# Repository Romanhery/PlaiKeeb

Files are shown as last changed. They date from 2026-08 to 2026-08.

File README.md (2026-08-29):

<h1>Plai-Keeb</h1>
Plai Keeb is a custom keyboard 75 % exploded keyboard with a rotary encoder and macro keys.
<h2>Features:</h2>
<ul>
   <li>Switched Rotary Encoder for volume control</li>
   <li>4 macro keys</li>
   <li>Candy Holder</li>
</ul>
<h2>PCB:</h2>
   <h2>Schematic</h2>
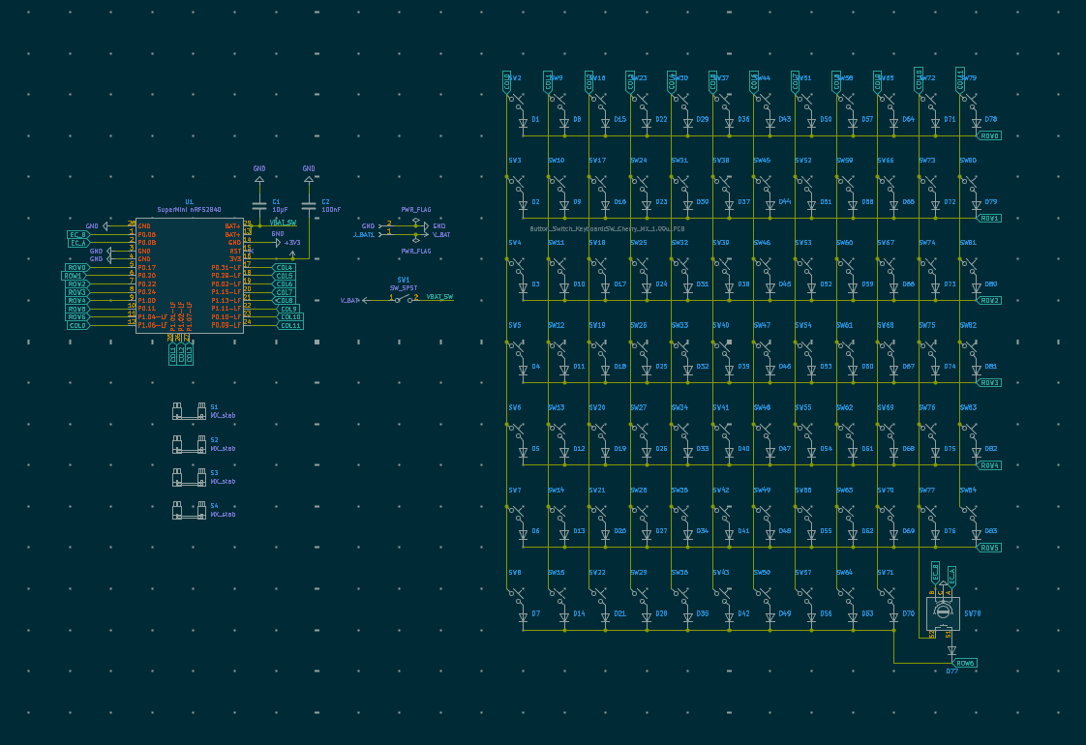
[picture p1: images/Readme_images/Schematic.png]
Schematic
   
   <h2>PCB</h2>
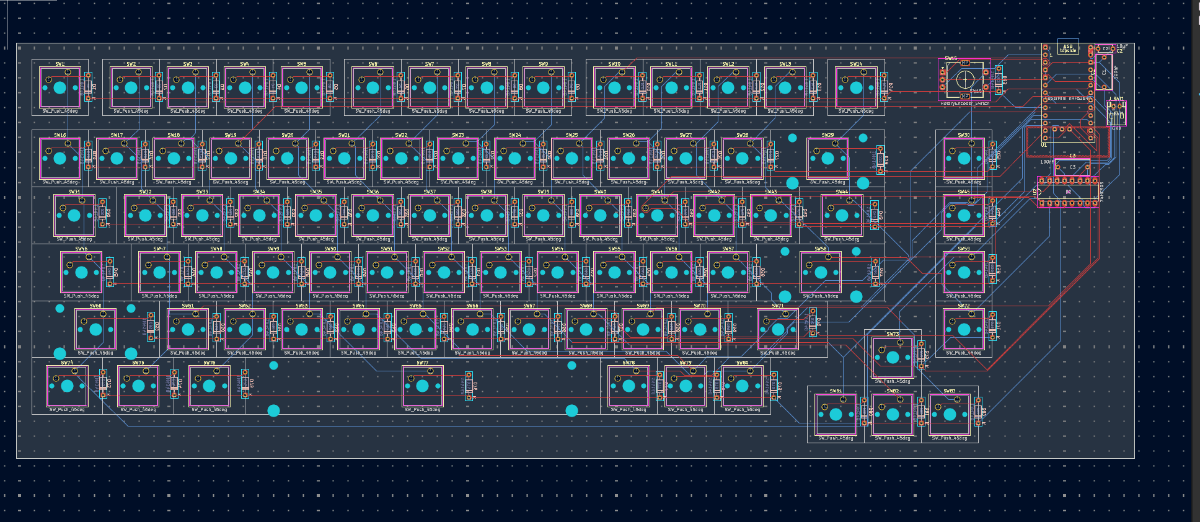
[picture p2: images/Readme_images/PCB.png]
PCB
   
   <p>Made in <a href="https://www.kicad.org/">Ki-CAD</a></p> 

<h2>CAD:</h2>
   <p>Everything is held together by using 6 M3 Bolts and heated inserts.</p>
   <p>It has 2 printed pieces and a plate to cover the electronics and house them.</p>
   <p>Made in Fusion 360</p>
<p align="center">
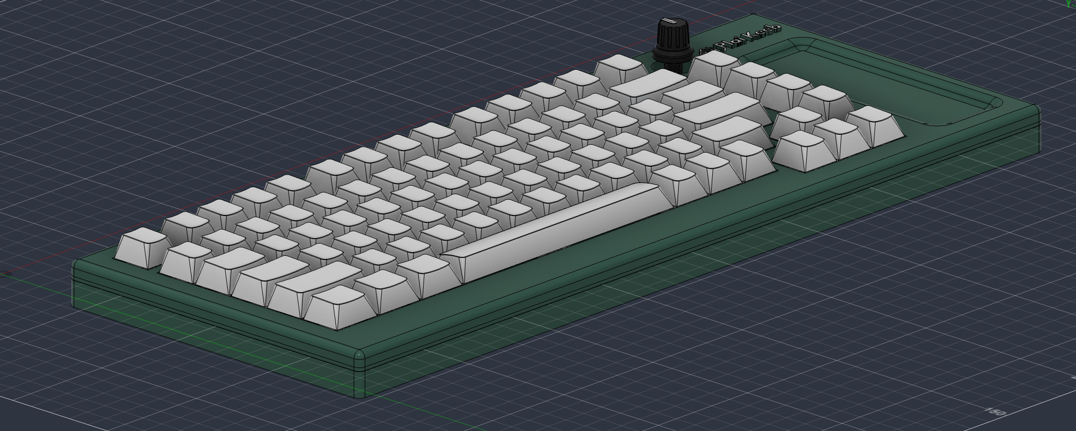
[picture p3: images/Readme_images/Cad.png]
Plai CAD Render
  
</p>
<h2>Firmware:</h2>
   <p>Made with <a href="https://github.com/KMKfw/kmk_firmware">KMK</a> firmware</p> 
   <h3>Features</h3>
   <li>Volume control if you twist the rotary encoder and if you press the encoder to mute</li>
   <li>It has macros for any shorcut you want!</li>
   <p align="center">
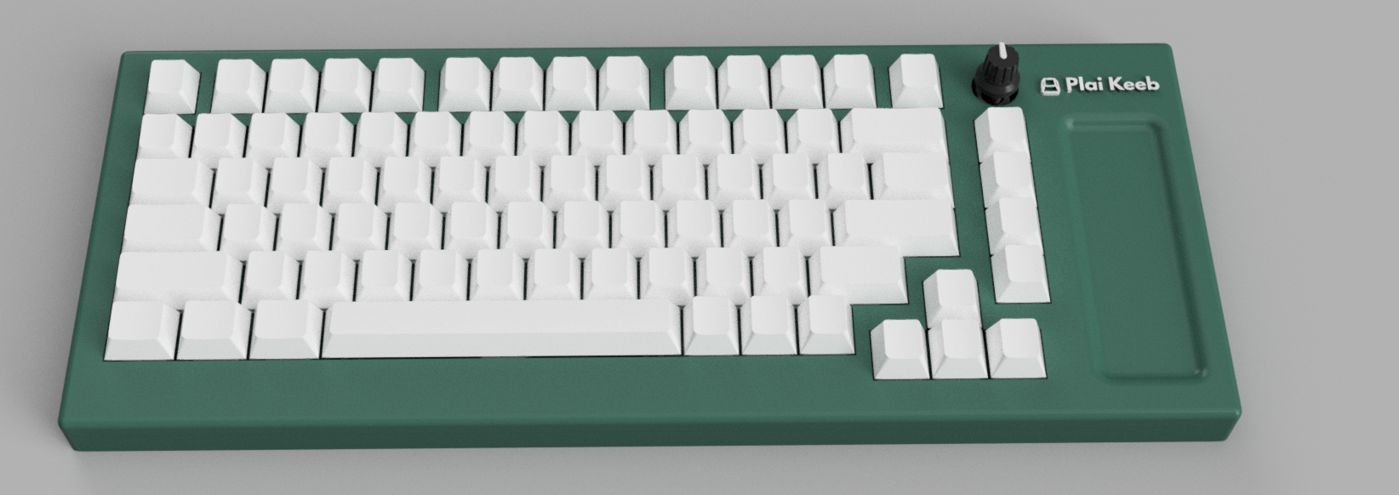
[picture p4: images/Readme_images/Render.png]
  
   </p>
<h2>BOM:</h2>
<p>Everything you need to make this macro pad is here!</p>
<ul>
    <li>9x Cherry MX Switches</li>
    <li>9x DSA Keycaps</li>
    <li>5x M3x5x4 Heatset inserts</li>
    <li>4x M3x16mm SHCS Bolts</li>
    <li>9x 1N4148 DO-35 Diodes.</li>
    <li>1x 0.91" OLED Display</li>
    <li>1x EC11 Rotary Encoder</li>
    <li>1x XIAO RP2040</li>
    <li>1x Case (2 printed parts)</li>
   <a href="https://docs.google.com/spreadsheets/d/1uIeMTGPOrdSAiFDxR4G393WpXhlTQVRrd_AwqsaPwl4/edit?usp=sharing">BOM HERE WITH LINKS</a>
</ul>
<h2>Acknowledgements</h2> 

* [Keeb](https://github.com/hackclub/hackpad/tree/main/cad/orpheuspad)
* [Void Pointer](https://github.com/Mirai-09/Keybie-Hackpads)
## Authors
- [@Romanhery](https://github.com/Romanhery)

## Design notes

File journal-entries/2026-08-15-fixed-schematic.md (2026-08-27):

# Fixed Schematic

📅 **2026-08-15** · 🕐 **23:03** · ⏱️ **1h logged**  

---
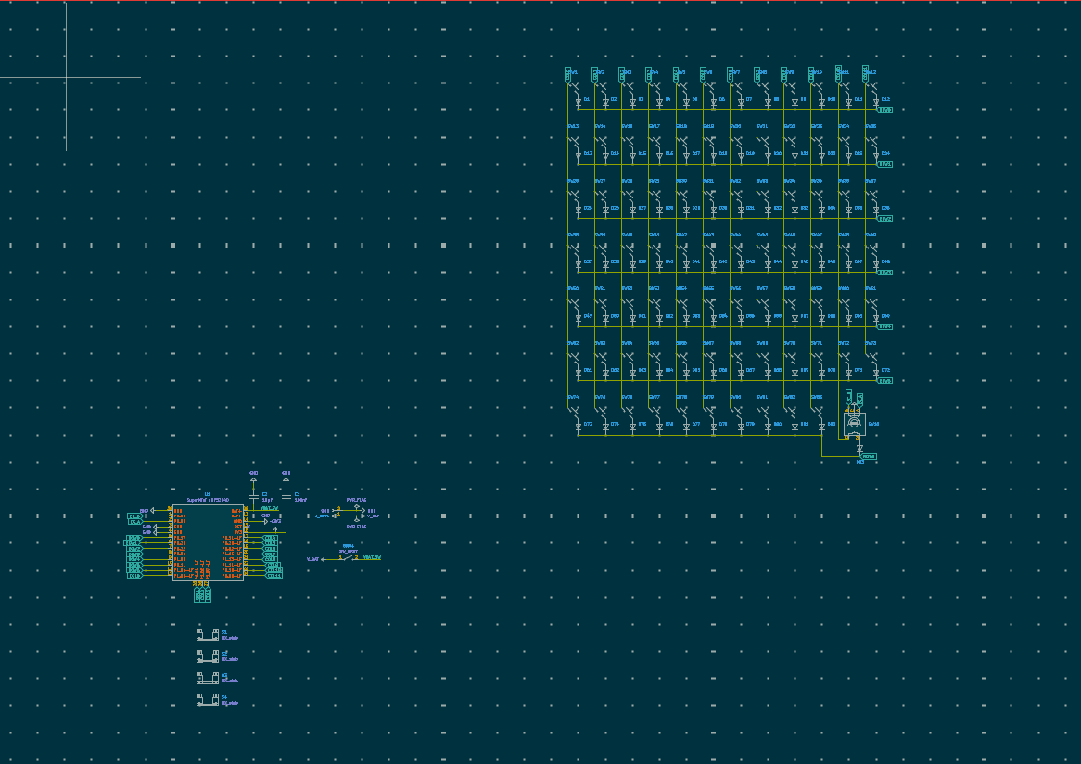
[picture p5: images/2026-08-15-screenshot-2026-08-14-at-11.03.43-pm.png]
Screenshot 2026-08-14 at 11.03.43 PM.png

I refactored the collumns and the rows so that they use 2 less pins which were what I needed instead of the hard to code shift register or io extender and I have more space on my keyboard too. I learned that sometimes you just need to go back the the fundementals and build that first better.

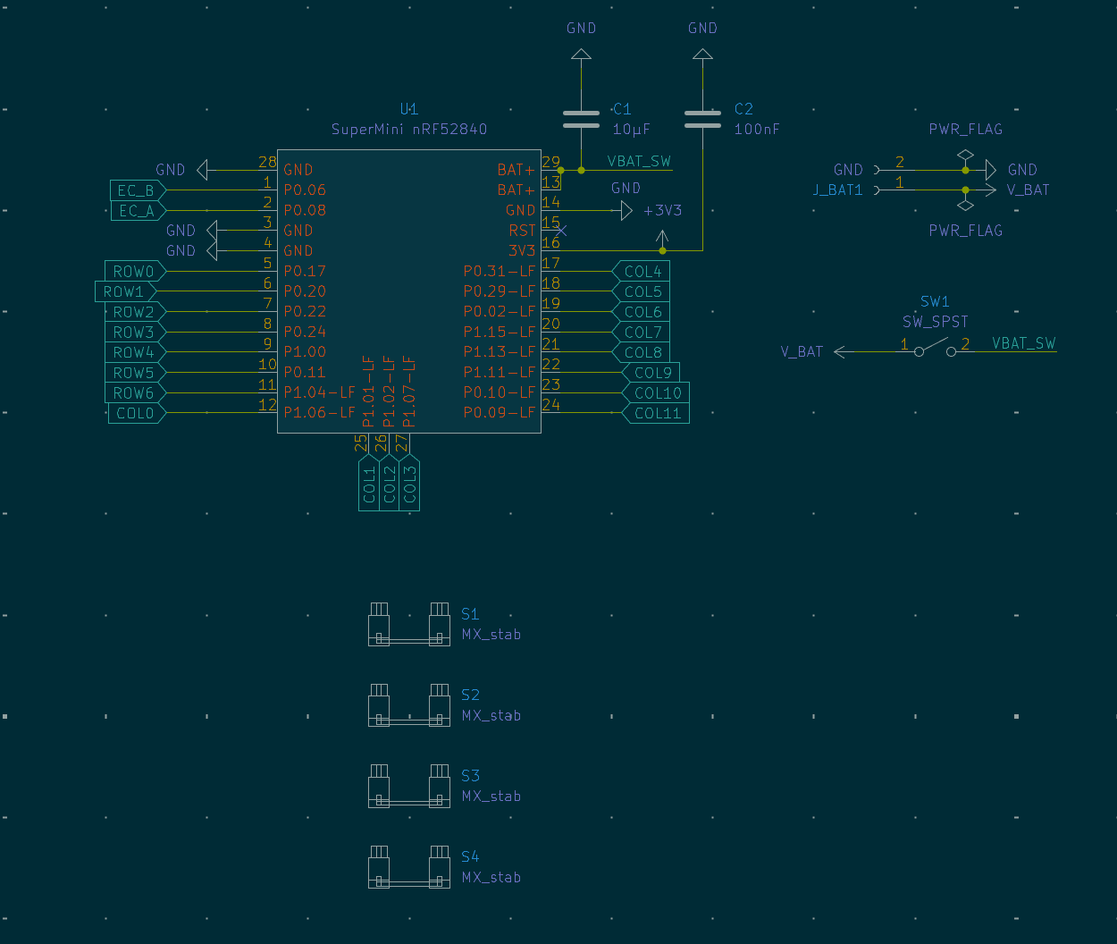
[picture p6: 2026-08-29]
images/Readme_images/Microcontroller.png

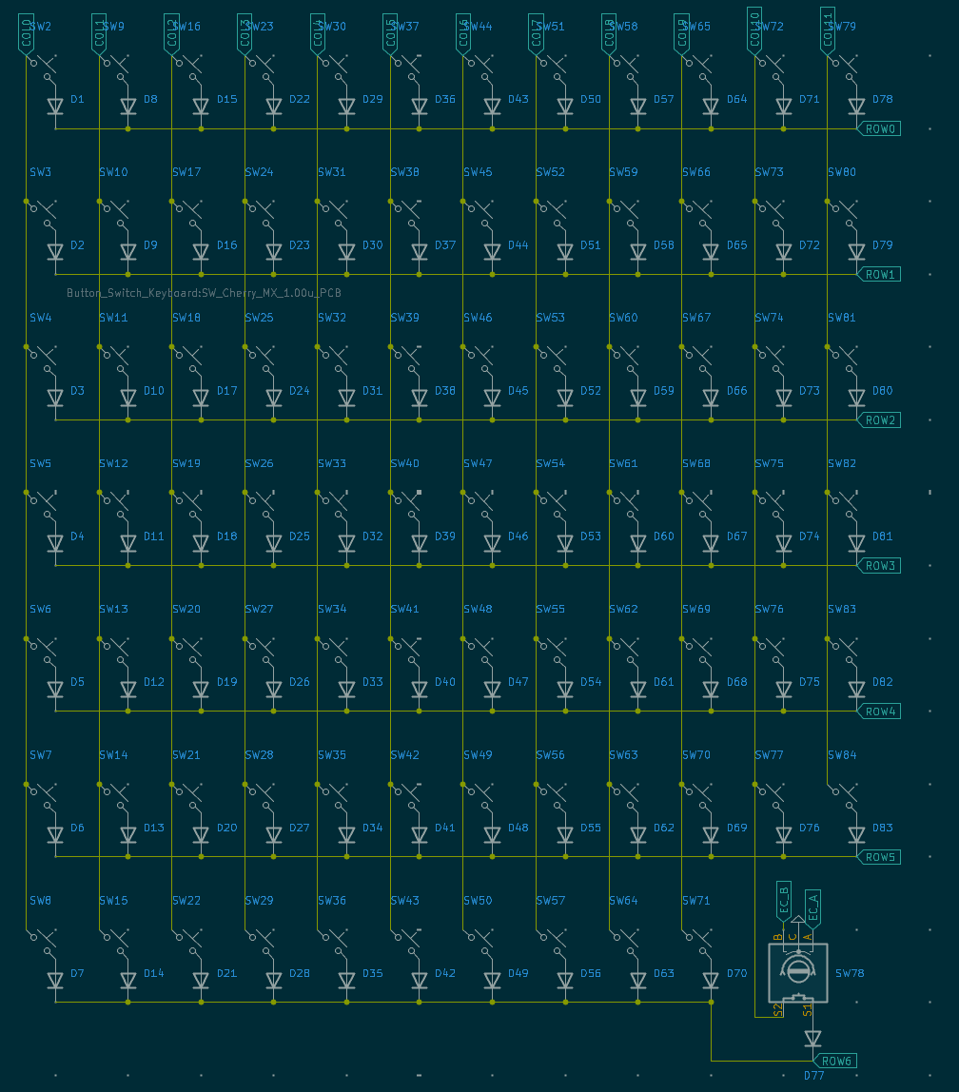
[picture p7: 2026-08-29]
images/Readme_images/Key_matrix.png

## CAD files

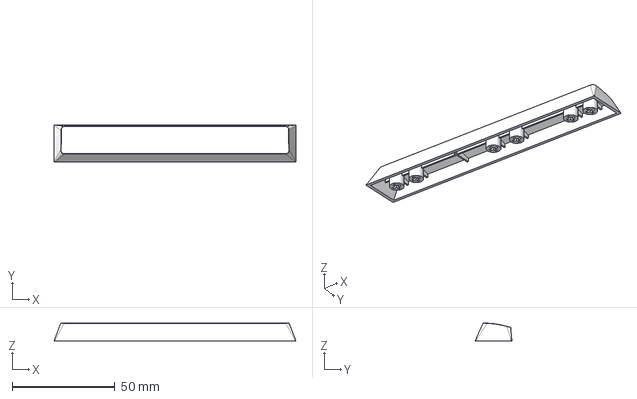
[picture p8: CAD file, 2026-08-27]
Case/3d-Models/6.25u keycap.step
118.0 x 18.0 x 8.70 mm

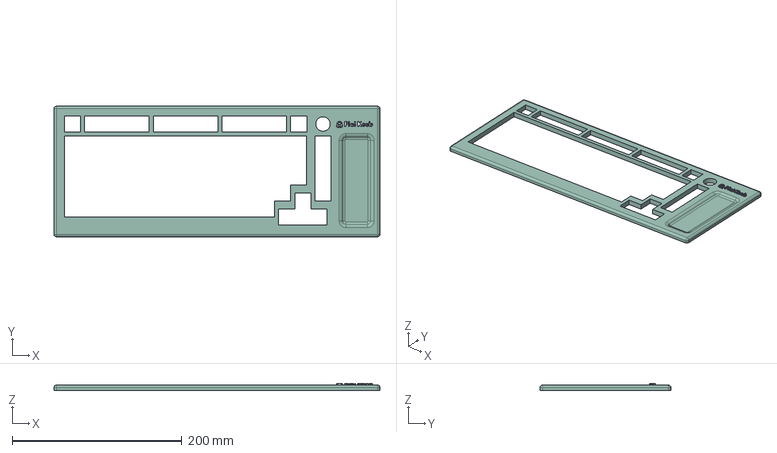
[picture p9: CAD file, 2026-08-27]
Case/Keeboard_Top_Cover.step
384.0 x 154.0 x 7.90 mm

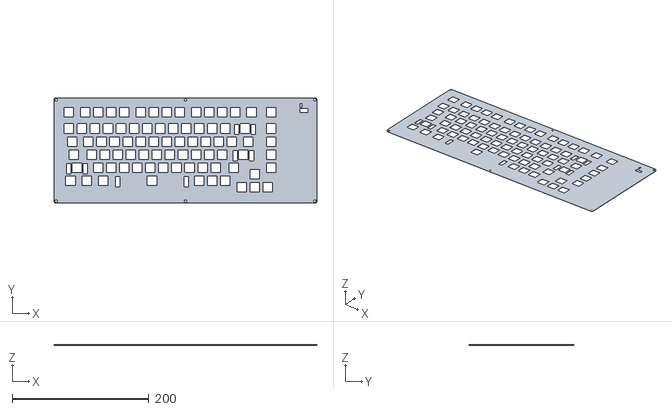
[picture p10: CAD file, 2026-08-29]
Production/Case_Production/Plate.stl
384.0 x 154.0 x 1.50

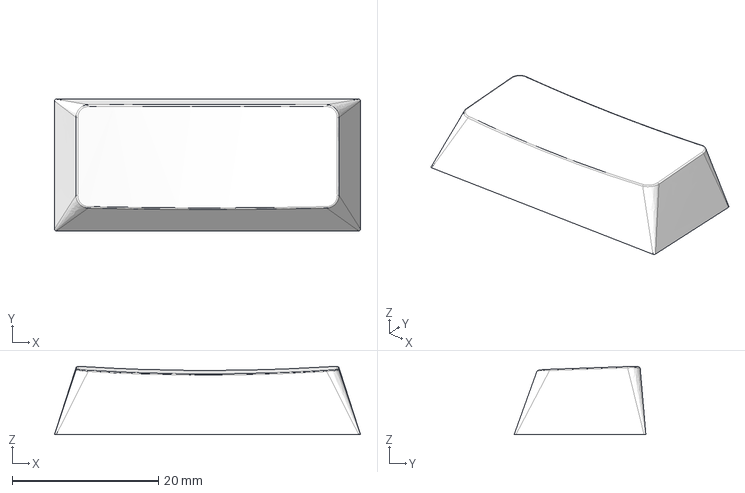
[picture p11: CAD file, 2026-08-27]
Case/3d-Models/2.25u keycap.step
41.8 x 18.0 x 9.30 mm

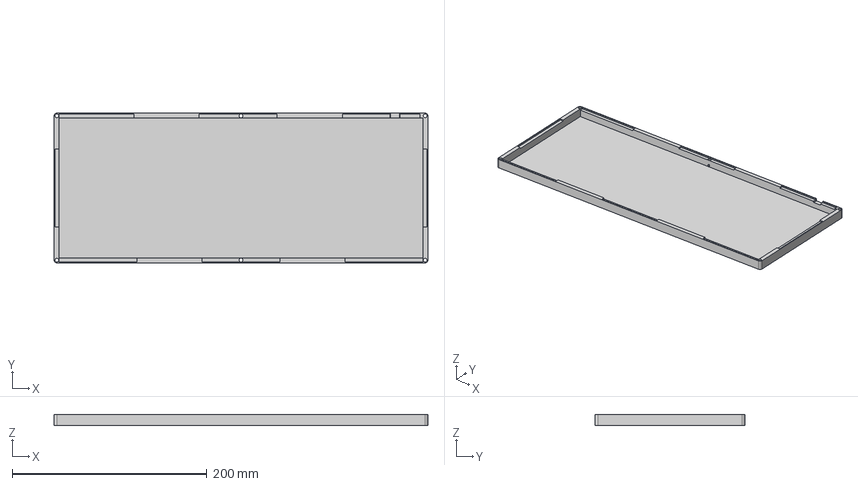
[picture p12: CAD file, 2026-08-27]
Case/Bottom_Case.step
384.0 x 154.0 x 11.0 mm

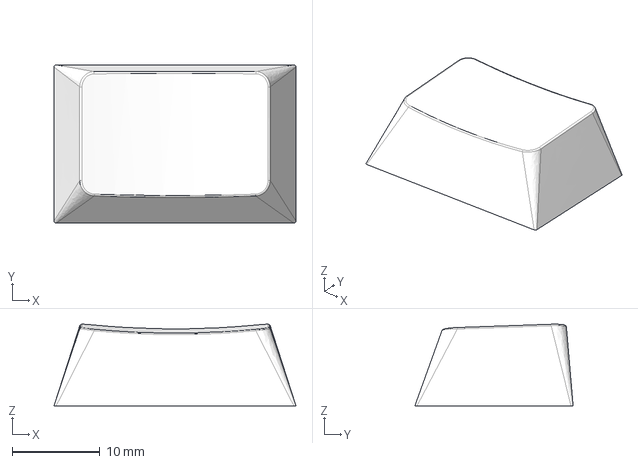
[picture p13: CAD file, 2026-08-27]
Case/3d-Models/1.5u keycap.step
27.5 x 18.0 x 9.28 mm

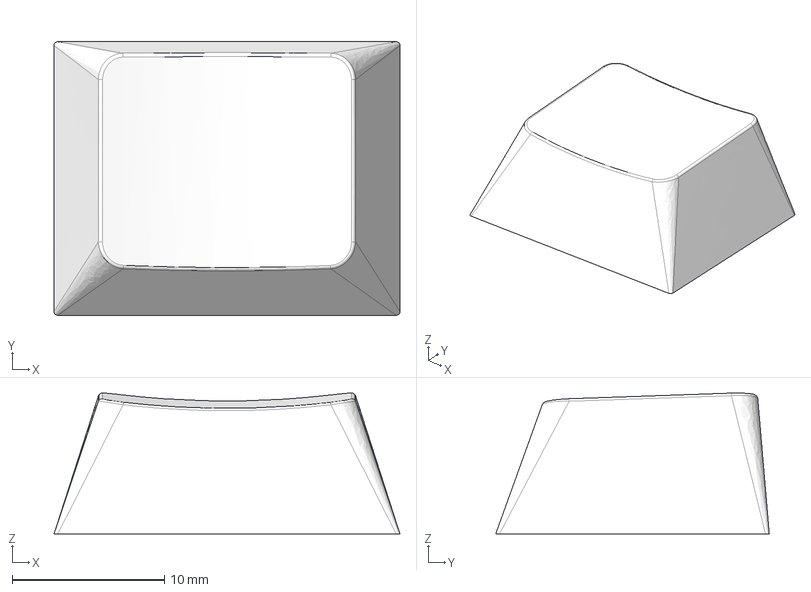
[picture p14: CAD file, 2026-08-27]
Case/3d-Models/1.25u keycap.step
22.8 x 18.0 x 9.27 mm

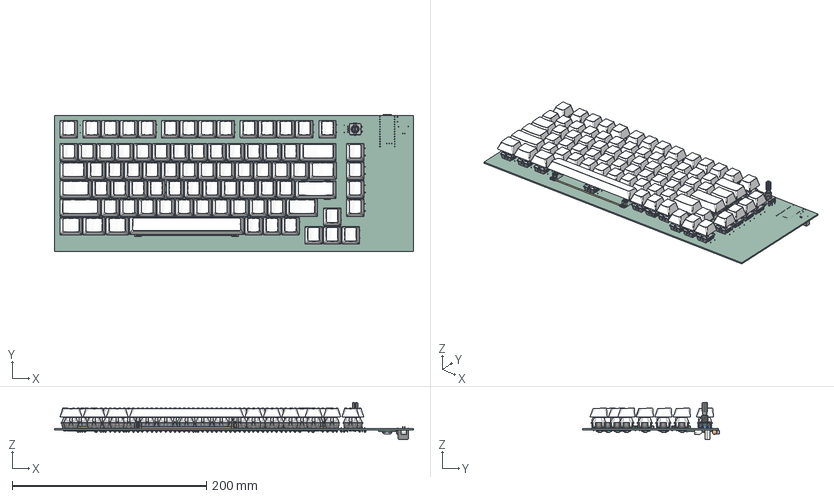
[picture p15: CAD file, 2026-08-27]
Case/3d-Models/Keyboard.step
370.0 x 140.7 x 38.3 mm
Bottom x 82
Pulsador x 82
Top x 82
Pieza5^Cherry MX x 82
Pin1 x 82
Pin2 x 82
Led 3mm_trans x 82
1u x 71
1.25u keycap x 3
1.75u keycap x 2
1.5u keycap x 2
EC11_Rotary_Encoder_Switched
D_DO-35_SOD27_P7.62mm_Horizontal x 83
Stabilizer Housing x 8
M2 Insert x 8
Stabilizer Insert x 8
6.25U Stabilizer Bar
6.25u keycap
2U Stabilizer Bar x 3
2.25u keycap x 2
2u keycap
C_Rect_L115mm_W52mm_P1000mm_MKT
ProMicro NRF52840 AUYXSSZ
C_Disc_D47mm_W25mm_P500mm
JST_S2B_PH_K
PlaiKeyboard_PCB

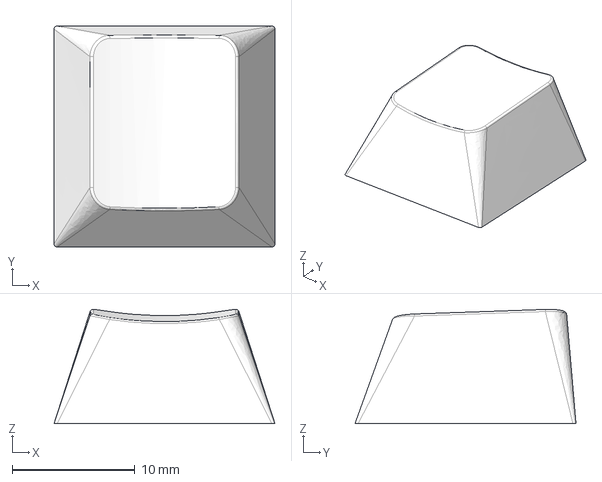
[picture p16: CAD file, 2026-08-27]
Case/3d-Models/1u Keycap.step
18.0 x 18.0 x 9.30 mm

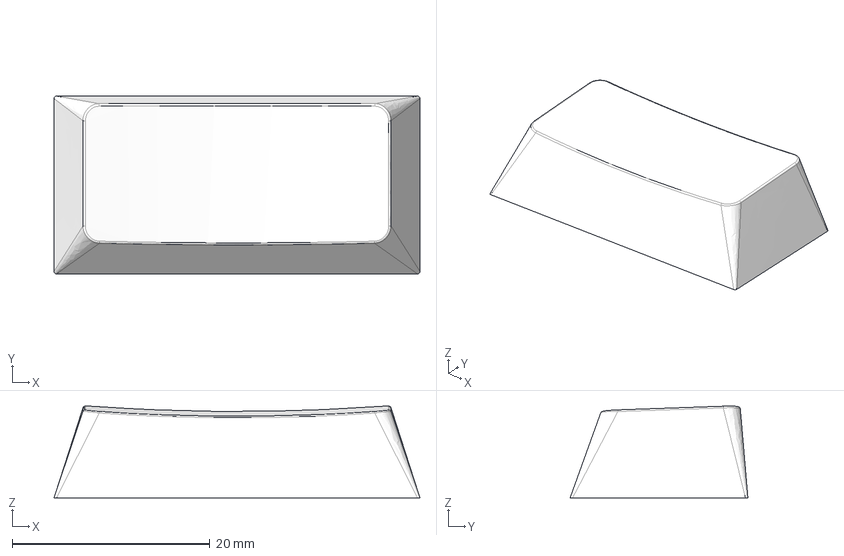
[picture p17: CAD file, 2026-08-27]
Case/3d-Models/2u keycap.step
37.1 x 18.0 x 9.29 mm

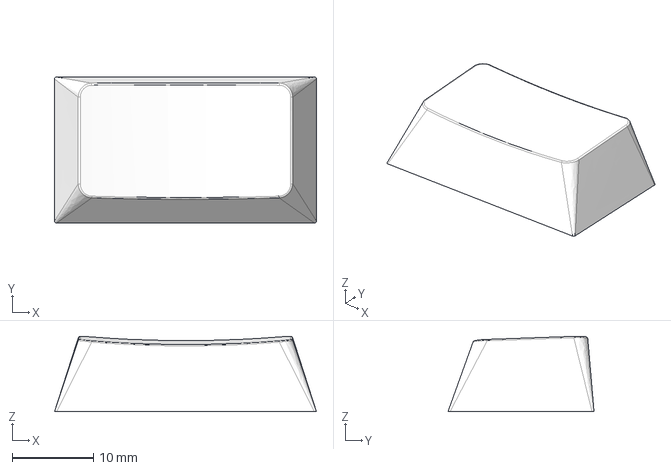
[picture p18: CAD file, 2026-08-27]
Case/3d-Models/1.75u keycap.step
32.3 x 18.0 x 9.29 mm

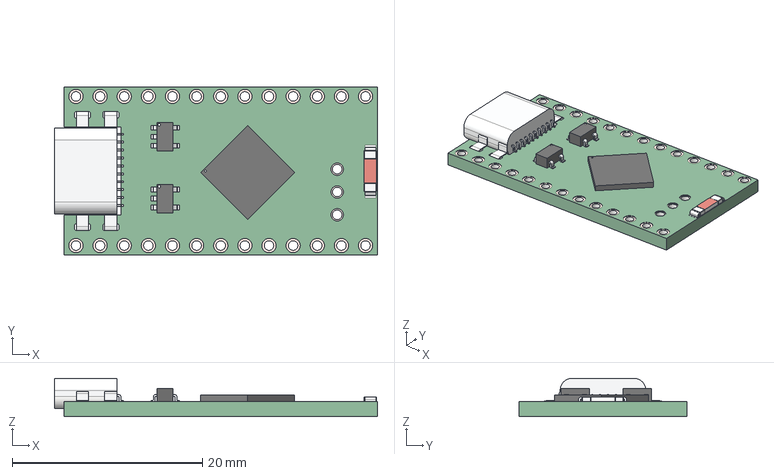
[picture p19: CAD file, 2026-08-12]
Case/3d-Models/ProMicro NRF52840 AUYXSSZ.step
34.0 x 17.7 x 4.05 mm

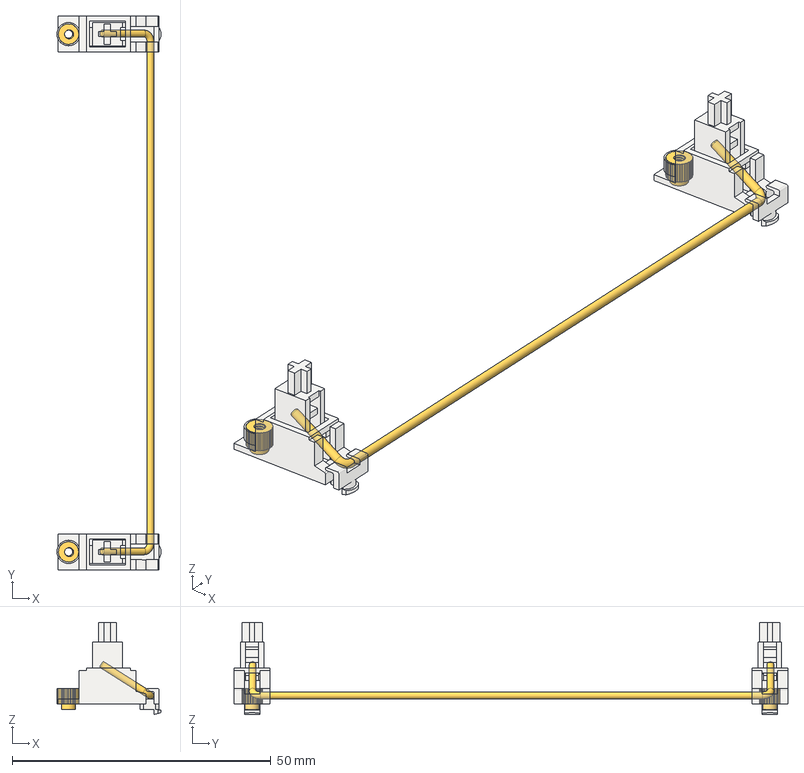
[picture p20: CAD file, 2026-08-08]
Case/3d-Models/6.25U Stabilizer.step
20.1 x 107.0 x 17.8 mm
Stabilizer Housing x 2
M2 Insert x 2
Stabilizer Insert x 2
6.25U Stabilizer Bar

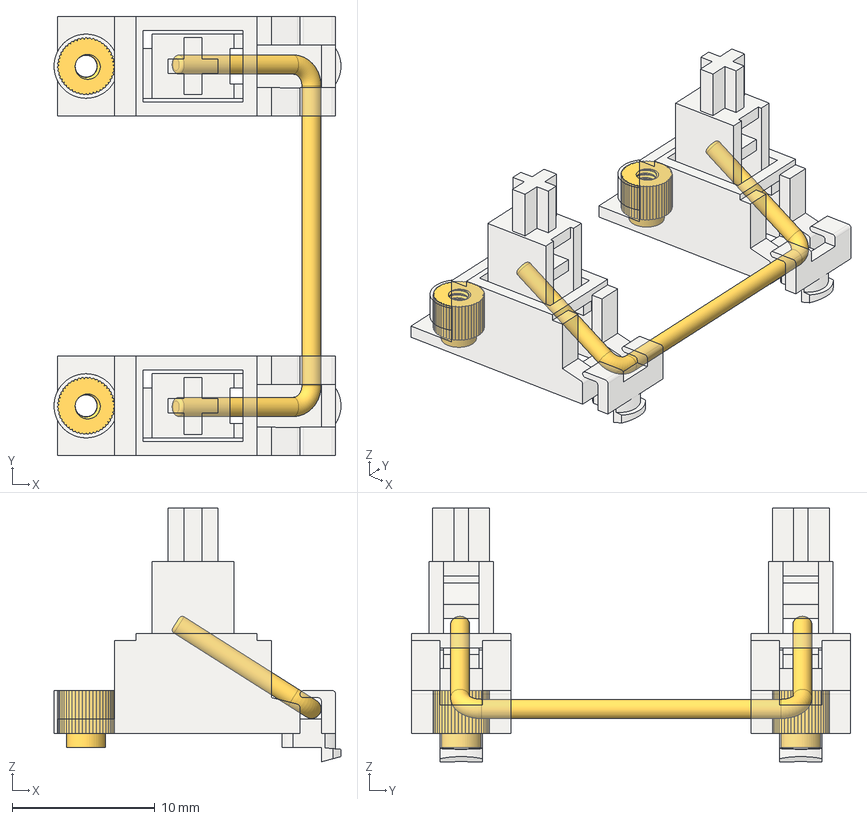
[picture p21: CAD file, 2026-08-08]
Case/3d-Models/2U Stabilizer.step
20.1 x 30.8 x 17.8 mm
Stabilizer Housing x 2
M2 Insert x 2
Stabilizer Insert x 2
2U Stabilizer Bar

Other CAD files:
Production/Case_Production/Bottom_Case.stl
Case/Plate.step
Production/Case_Production/Top_Case.stl
Case/3d-Models/Cherry-MX.STEP
Case/3d-Models/EC11_Rotary_Encoder_Switched.step

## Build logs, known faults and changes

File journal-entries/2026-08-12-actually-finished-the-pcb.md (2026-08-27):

# ACTUALLY FINISHED THE PCB

📅 **2026-08-12** · 🕐 **19:41** · ⏱️ **3h logged**  

---
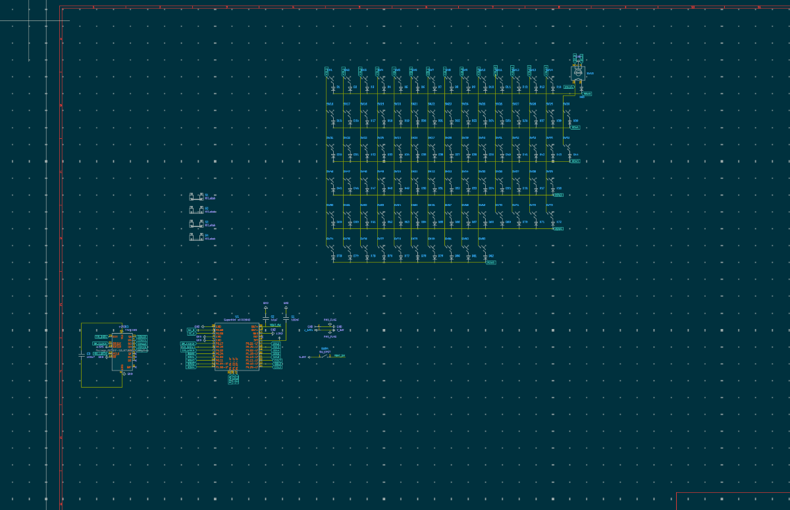
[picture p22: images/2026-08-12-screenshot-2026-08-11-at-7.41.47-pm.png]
Screenshot 2026-08-11 at 7.41.47 PM.png
Screenshot 2026-08-11 at 7.41.25 PM.png
I finished routing the pcb. I also added 3d models and debugged the routing. This was very very time consuming and very hard but I learned that instead of having to manually change 3d models of the switches i can just update the footprints original 3d model.

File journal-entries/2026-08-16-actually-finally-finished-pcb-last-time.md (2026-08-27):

# ACTUALLY FINALLY FINISHED PCB LAST TIME

📅 **2026-08-16** · 🕐 **18:08** · ⏱️ **3h logged**  

---
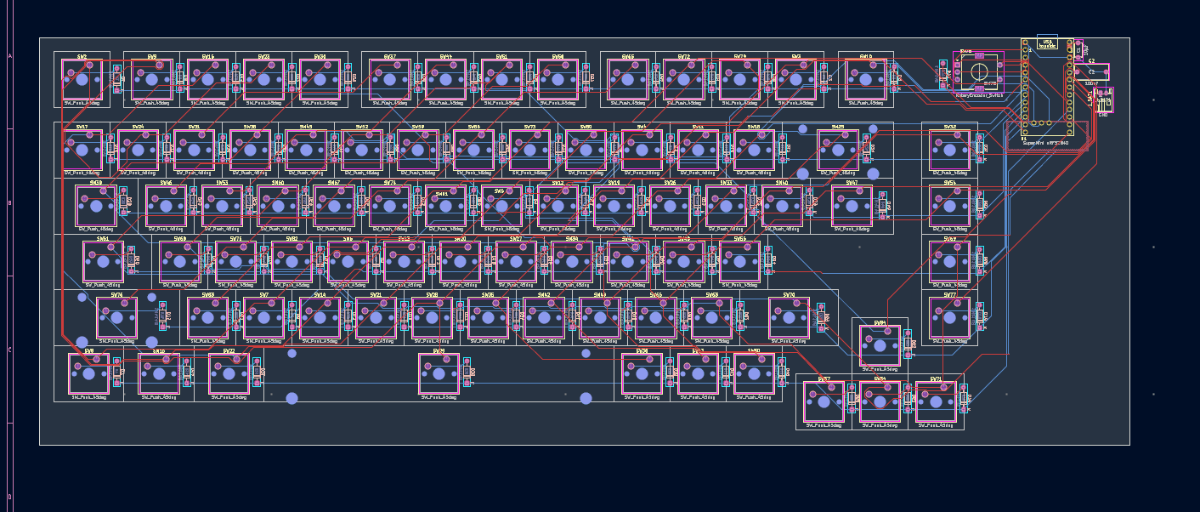
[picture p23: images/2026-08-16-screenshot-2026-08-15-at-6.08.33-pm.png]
Screenshot 2026-08-15 at 6.08.33 PM.png

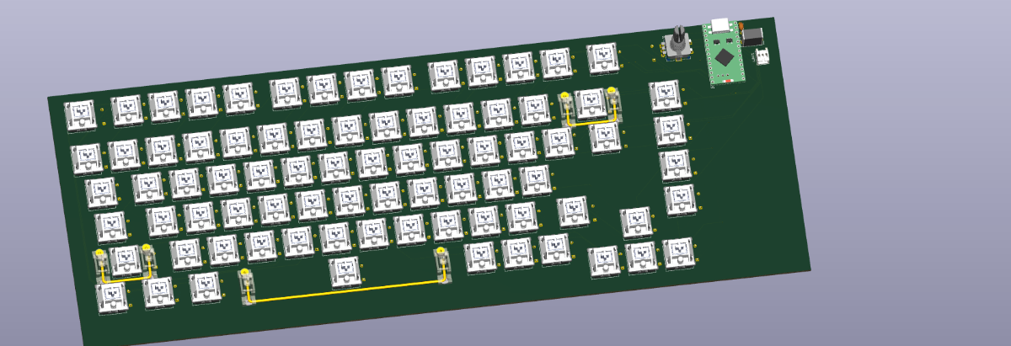
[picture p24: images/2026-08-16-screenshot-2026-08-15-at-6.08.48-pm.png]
Screenshot 2026-08-15 at 6.08.48 PM.png

Once again I was too paranoid of the pcb not working so I went back to the basic and fixed the fundemental schematic and made the matrix use less pins by transforming into it to a more square shape. After that I also routed the schematic over and over again like 3 times and landed on this one. After that I added the 3d models and am finally ready to start the CAD.

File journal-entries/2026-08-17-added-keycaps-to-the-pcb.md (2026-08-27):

# Added keycaps to the pcb

📅 **2026-08-17** · 🕐 **19:00** · ⏱️ **2h logged**  

---
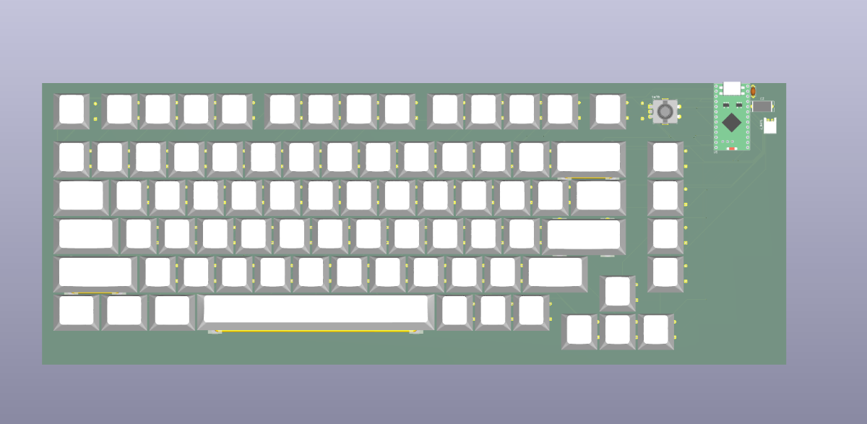
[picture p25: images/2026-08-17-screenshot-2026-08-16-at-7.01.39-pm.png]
Screenshot 2026-08-16 at 7.01.39 PM.png

Originally I tried to add keycaps to the pcb in Fusion but when I added them it would run very very slowly so I came to kicad and added the 3d models of the keycaps here on the switches. I also didn't like how the pcb was orignally too off centered so fixed the place where it was and moved it to the top of the last collumn and first row.

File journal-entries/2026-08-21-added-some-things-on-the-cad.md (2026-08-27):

# Added some things on the cad

📅 **2026-08-21** · 🕐 **23:39** · ⏱️ **2h logged**  

---
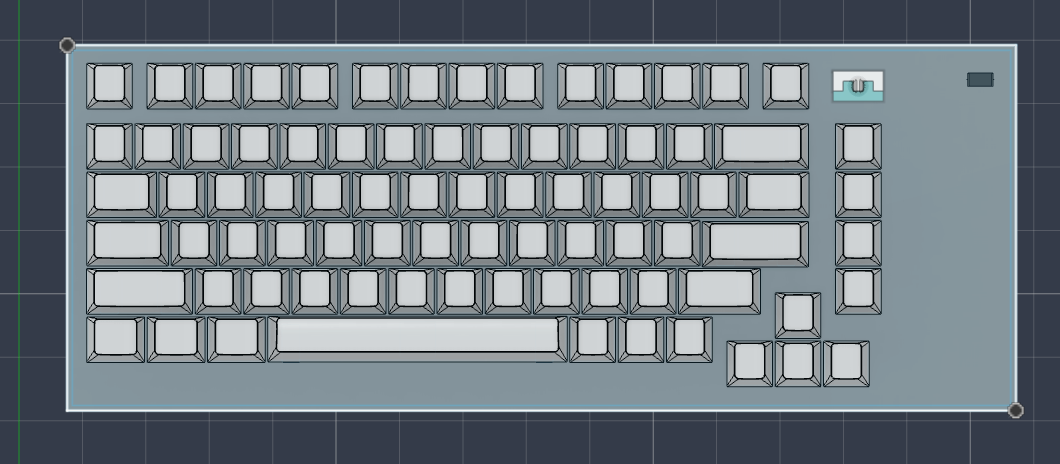
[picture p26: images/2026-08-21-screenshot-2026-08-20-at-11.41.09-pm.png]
Screenshot 2026-08-20 at 11.41.09 PM.png

Added the top frame and cutout them. I am going to be making a cooler design in the future. Also I added the rotary knob cap. Also I fixed some overhang that the plate had. Also I fixed this weird thing that looked weird and finished it

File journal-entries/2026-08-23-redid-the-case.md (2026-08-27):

# Redid the case

📅 **2026-08-23** · 🕐 **01:02** · ⏱️ **2h logged**  

---
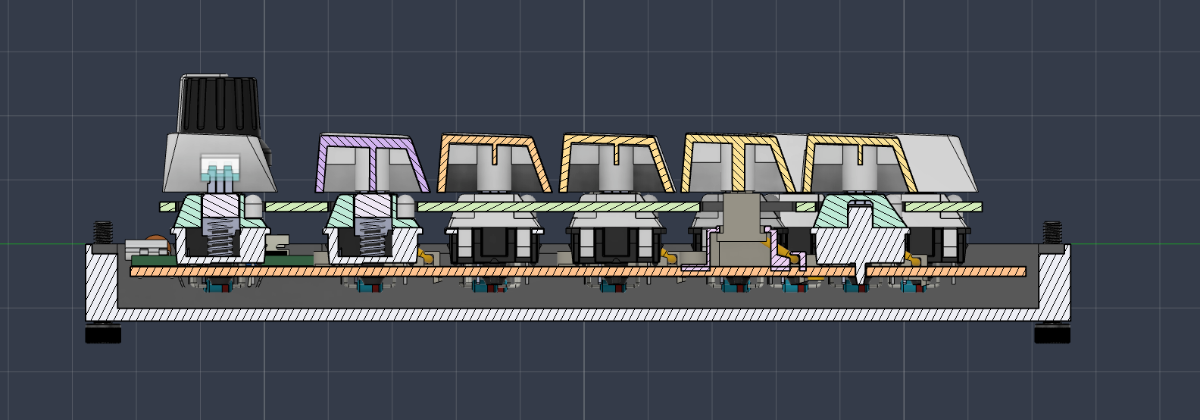
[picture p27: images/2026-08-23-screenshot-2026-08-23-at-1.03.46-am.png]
Screenshot 2026-08-23 at 1.03.46 AM.png

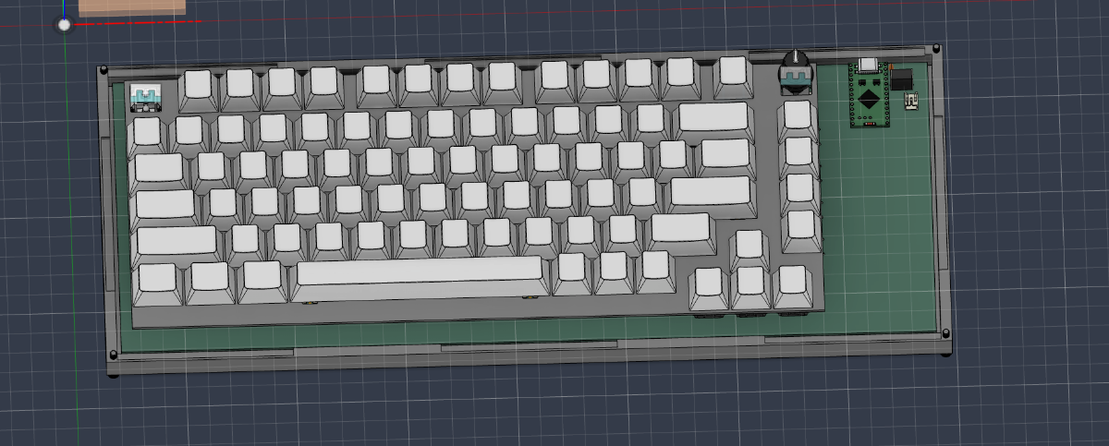
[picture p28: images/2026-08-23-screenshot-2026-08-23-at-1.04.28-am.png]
Screenshot 2026-08-23 at 1.04.28 AM.png

I redid the whole case because I forgot to add the gasket mount and I also was following the wrong guide. I added spaces for the gaskets to go to added screws and added the plate correctly. I also made it actually look better than the last.

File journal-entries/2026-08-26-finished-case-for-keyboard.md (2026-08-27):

# Finished Case For Keyboard

📅 **2026-08-26** · 🕐 **21:50** · ⏱️ **3h logged**  

---
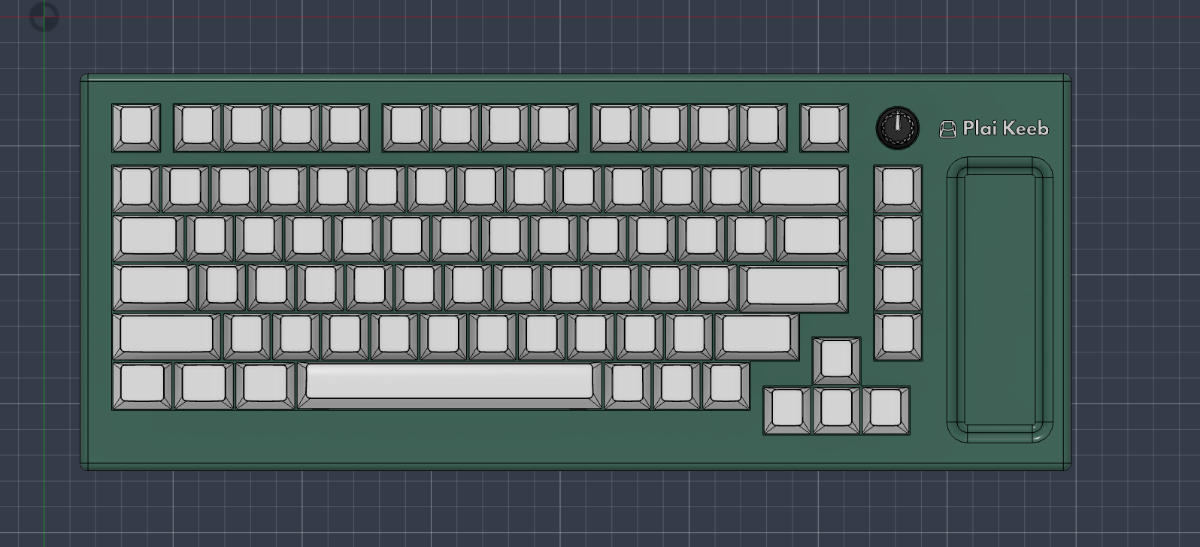
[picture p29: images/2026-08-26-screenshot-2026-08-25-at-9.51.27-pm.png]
Screenshot 2026-08-25 at 9.51.27 PM.png

I FINALLY Finished the keyboard's case and everything. I added the screw holes and made them perfectly even and added heatset inserts. I also added a candy holder that can fit m&ms and skittles to make it a little more creative. I also colored it what I might want to make it look like.

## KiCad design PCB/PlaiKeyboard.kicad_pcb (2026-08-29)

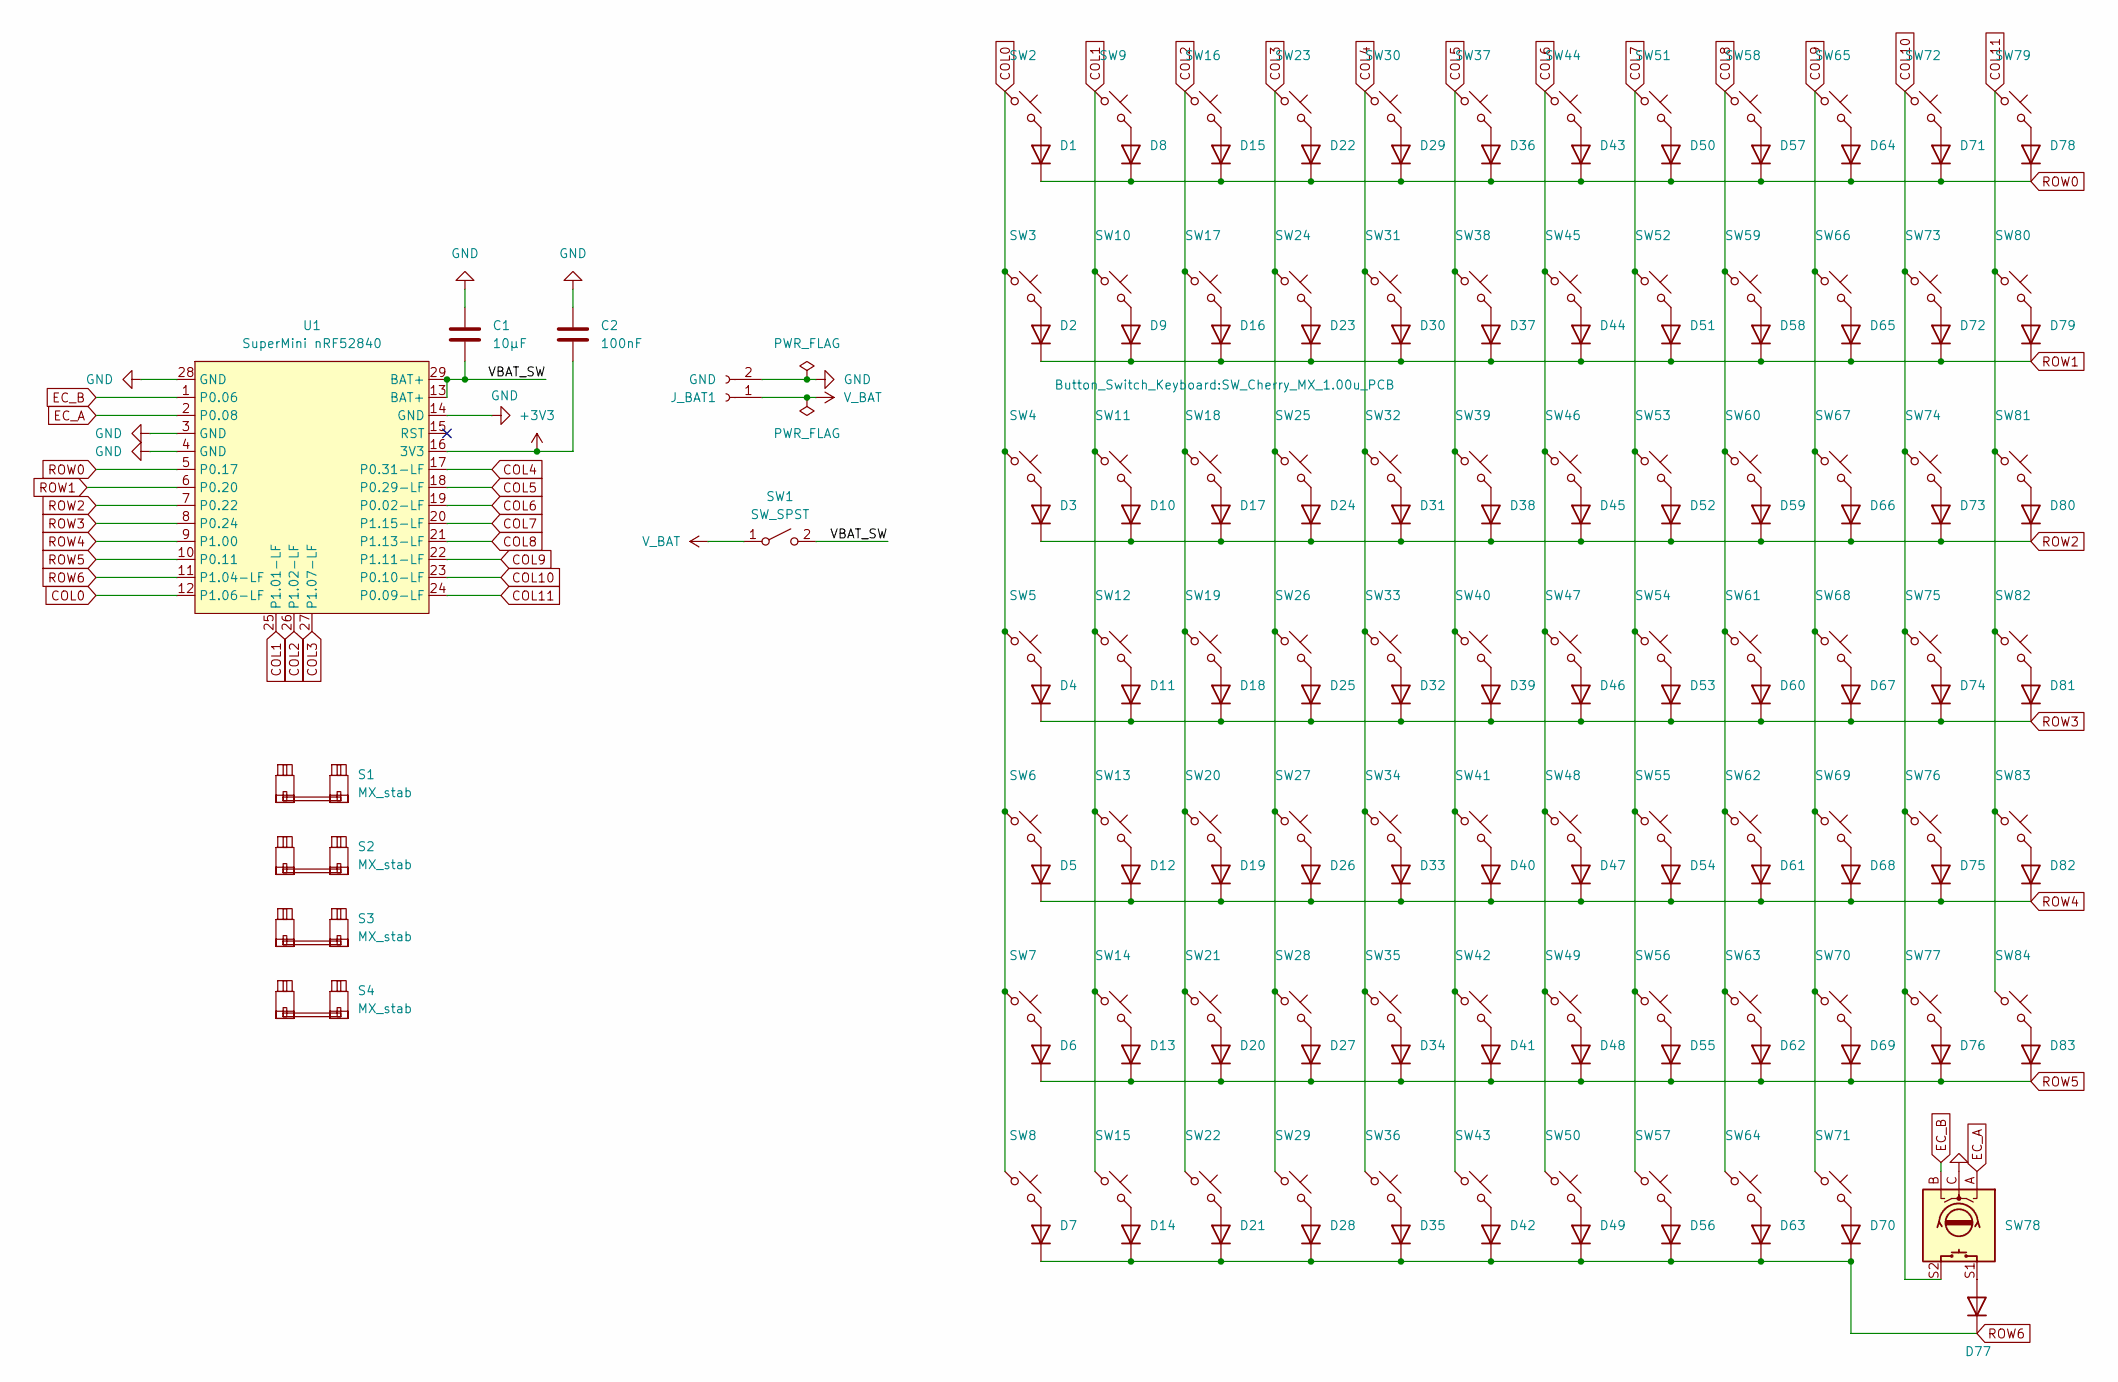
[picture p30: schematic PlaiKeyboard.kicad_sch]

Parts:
C1: 10µF; C_Disc_D4.7mm_W2.5mm_P5.00mm
C2: 100nF; C_Rect_L11.5mm_W5.2mm_P10.00mm_MKT
D1, D2, D3, D4, D5, D6, D7, D8, D9, D10, D11, D12, D13, D14, D15, D16, D17, D18, D19, D20, D21, D22, D23, D24, D25, D26, D27, D28, D29, D30, D31, D32, D33, D34, D35, D36, D37, D38, D39, D40, D41, D42, D43, D44, D45, D46, D47, D48, D49, D50, D51, D52, D53, D54, D55, D56, D57, D58, D59, D60, D61, D62, D63, D64, D65, D66, D67, D68, D69, D70, D71, D72, D73, D74, D75, D76, D77, D78, D79, D80, D81, D82, D83: 1N4148; D_DO-35_SOD27_P7.62mm_Horizontal
J_BAT1: GND; JST_PH_S2B-PH-K_1x02_P2.00mm_Horizontal
S1: MX_stab; STAB_MX_P_6.25u
S2, S3: MX_stab; STAB_MX_2.25u
S4: MX_stab; STAB_MX_2u
SW1: SW_SPST; 1P2T_SS-12D00_CNK
SW2, SW3, SW4, SW5, SW6, SW7, SW9, SW10, SW11, SW12, SW13, SW14, SW16, SW17, SW18, SW19, SW20, SW21, SW23, SW24, SW26, SW27, SW28, SW30, SW31, SW32, SW33, SW34, SW35, SW36, SW37, SW38, SW40, SW41, SW42, SW43, SW44, SW45, SW46, SW48, SW49, SW50, SW51, SW52, SW53, SW54, SW55, SW56, SW57, SW58, SW59, SW60, SW63, SW64, SW65, SW66, SW67, SW68, SW69, SW71, SW72, SW73, SW74, SW75, SW77, SW79, SW80, SW81, SW82, SW83, SW84: SW_Push_45deg; SW_Cherry_MX_1.00u_PCB
SW8, SW15, SW22: SW_Push_45deg; SW_Cherry_MX_1.25u_PCB
SW25: SW_Push_45deg; SW_Cherry_MX_2.00u_PCB
SW29: SW_Push_45deg; SW_Cherry_MX_6.25u_PCB
SW39, SW47: SW_Push_45deg; SW_Cherry_MX_1.50u_PCB
SW61, SW70: SW_Push_45deg; SW_Cherry_MX_1.75u_PCB
SW62, SW76: SW_Push_45deg; SW_Cherry_MX_2.25u_PCB
SW78: RotaryEncoder_Switch; RotaryEncoder_Alps_EC11E-Switch_Vertical_H20mm
U1: SuperMini nRF52840; SuperMini_nRF52840_AH_USBup

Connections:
+3V3: C2.1, U1.16 (3V3)
/VBAT_SW: C1.2, SW1.2 (B), U1.13 (BAT+), U1.29 (BAT+)
COL0: SW2.1, SW3.1, SW4.1, SW5.1, SW6.1, SW7.1, SW8.1, U1.12 (P1.06-LF)
COL1: SW9.1, SW10.1, SW11.1, SW12.1, SW13.1, SW14.1, SW15.1, U1.25 (P1.01-LF)
COL2: SW16.1, SW17.1, SW18.1, SW19.1, SW20.1, SW21.1, SW22.1, U1.26 (P1.02-LF)
COL3: SW23.1, SW24.1, SW25.1, SW26.1, SW27.1, SW28.1, SW29.1, U1.27 (P1.07-LF)
COL4: SW30.1, SW31.1, SW32.1, SW33.1, SW34.1, SW35.1, SW36.1, U1.17 (P0.31-LF)
COL5: SW37.1, SW38.1, SW39.1, SW40.1, SW41.1, SW42.1, SW43.1, U1.18 (P0.29-LF)
COL6: SW44.1, SW45.1, SW46.1, SW47.1, SW48.1, SW49.1, SW50.1, U1.19 (P0.02-LF)
COL7: SW51.1, SW52.1, SW53.1, SW54.1, SW55.1, SW56.1, SW57.1, U1.20 (P1.15-LF)
COL8: SW58.1, SW59.1, SW60.1, SW61.1, SW62.1, SW63.1, SW64.1, U1.21 (P1.13-LF)
COL9: SW65.1, SW66.1, SW67.1, SW68.1, SW69.1, SW70.1, SW71.1, U1.22 (P1.11-LF)
COL10: SW72.1, SW73.1, SW74.1, SW75.1, SW76.1, SW77.1, SW78.S2, U1.23 (P0.10-LF)
COL11: SW79.1, SW80.1, SW81.1, SW82.1, SW83.1, SW84.1, U1.24 (P0.09-LF)
EC_A: SW78.A, U1.2 (P0.08)
EC_B: SW78.B, U1.1 (P0.06)
GND: C1.1, C2.2, J_BAT1.2, SW78.C, U1.3 (GND), U1.4 (GND), U1.14 (GND), U1.28 (GND)
unnamed: D1.2 (A), SW2.2
unnamed: D2.2 (A), SW3.2
unnamed: D3.2 (A), SW4.2
unnamed: D4.2 (A), SW5.2
unnamed: D5.2 (A), SW6.2
unnamed: D6.2 (A), SW7.2
unnamed: D7.2 (A), SW8.2
unnamed: D8.2 (A), SW9.2
unnamed: D9.2 (A), SW10.2
unnamed: D10.2 (A), SW11.2
unnamed: D11.2 (A), SW12.2
unnamed: D12.2 (A), SW13.2
unnamed: D13.2 (A), SW14.2
unnamed: D14.2 (A), SW15.2
unnamed: D15.2 (A), SW16.2
unnamed: D16.2 (A), SW17.2
unnamed: D17.2 (A), SW18.2
unnamed: D18.2 (A), SW19.2
unnamed: D19.2 (A), SW20.2
unnamed: D20.2 (A), SW21.2
unnamed: D21.2 (A), SW22.2
unnamed: D22.2 (A), SW23.2
unnamed: D23.2 (A), SW24.2
unnamed: D24.2 (A), SW25.2
unnamed: D25.2 (A), SW26.2
unnamed: D26.2 (A), SW27.2
unnamed: D27.2 (A), SW28.2
unnamed: D28.2 (A), SW29.2
unnamed: D29.2 (A), SW30.2
unnamed: D30.2 (A), SW31.2
unnamed: D31.2 (A), SW32.2
unnamed: D32.2 (A), SW33.2
unnamed: D33.2 (A), SW34.2
unnamed: D34.2 (A), SW35.2
unnamed: D35.2 (A), SW36.2
unnamed: D36.2 (A), SW37.2
unnamed: D37.2 (A), SW38.2
unnamed: D38.2 (A), SW39.2
unnamed: D39.2 (A), SW40.2
unnamed: D40.2 (A), SW41.2
unnamed: D41.2 (A), SW42.2
unnamed: D42.2 (A), SW43.2
unnamed: D43.2 (A), SW44.2
unnamed: D44.2 (A), SW45.2
unnamed: D45.2 (A), SW46.2
unnamed: D46.2 (A), SW47.2
unnamed: D47.2 (A), SW48.2
unnamed: D48.2 (A), SW49.2
unnamed: D49.2 (A), SW50.2
unnamed: D50.2 (A), SW51.2
unnamed: D51.2 (A), SW52.2
unnamed: D52.2 (A), SW53.2
unnamed: D53.2 (A), SW54.2
unnamed: D54.2 (A), SW55.2
unnamed: D55.2 (A), SW56.2
unnamed: D56.2 (A), SW57.2
unnamed: D57.2 (A), SW58.2
unnamed: D58.2 (A), SW59.2
unnamed: D59.2 (A), SW60.2
unnamed: D60.2 (A), SW61.2
unnamed: D61.2 (A), SW62.2
unnamed: D62.2 (A), SW63.2
unnamed: D63.2 (A), SW64.2
unnamed: D64.2 (A), SW65.2
unnamed: D65.2 (A), SW66.2
unnamed: D66.2 (A), SW67.2
unnamed: D67.2 (A), SW68.2
unnamed: D68.2 (A), SW69.2
unnamed: D69.2 (A), SW70.2
unnamed: D70.2 (A), SW71.2
unnamed: D71.2 (A), SW72.2
unnamed: D72.2 (A), SW73.2
unnamed: D73.2 (A), SW74.2
unnamed: D74.2 (A), SW75.2
unnamed: D75.2 (A), SW76.2
unnamed: D76.2 (A), SW77.2
unnamed: D77.2 (A), SW78.S1
unnamed: D78.2 (A), SW79.2
unnamed: D79.2 (A), SW80.2
unnamed: D80.2 (A), SW81.2
unnamed: D81.2 (A), SW82.2
unnamed: D82.2 (A), SW83.2
unnamed: D83.2 (A), SW84.2
ROW0: D1.1 (K), D8.1 (K), D15.1 (K), D22.1 (K), D29.1 (K), D36.1 (K), D43.1 (K), D50.1 (K), D57.1 (K), D64.1 (K), D71.1 (K), D78.1 (K), U1.5 (P0.17)
ROW1: D2.1 (K), D9.1 (K), D16.1 (K), D23.1 (K), D30.1 (K), D37.1 (K), D44.1 (K), D51.1 (K), D58.1 (K), D65.1 (K), D72.1 (K), D79.1 (K), U1.6 (P0.20)
ROW2: D3.1 (K), D10.1 (K), D17.1 (K), D24.1 (K), D31.1 (K), D38.1 (K), D45.1 (K), D52.1 (K), D59.1 (K), D66.1 (K), D73.1 (K), D80.1 (K), U1.7 (P0.22)
ROW3: D4.1 (K), D11.1 (K), D18.1 (K), D25.1 (K), D32.1 (K), D39.1 (K), D46.1 (K), D53.1 (K), D60.1 (K), D67.1 (K), D74.1 (K), D81.1 (K), U1.8 (P0.24)
ROW4: D5.1 (K), D12.1 (K), D19.1 (K), D26.1 (K), D33.1 (K), D40.1 (K), D47.1 (K), D54.1 (K), D61.1 (K), D68.1 (K), D75.1 (K), D82.1 (K), U1.9 (P1.00)
ROW5: D6.1 (K), D13.1 (K), D20.1 (K), D27.1 (K), D34.1 (K), D41.1 (K), D48.1 (K), D55.1 (K), D62.1 (K), D69.1 (K), D76.1 (K), D83.1 (K), U1.10 (P0.11)
ROW6: D7.1 (K), D14.1 (K), D21.1 (K), D28.1 (K), D35.1 (K), D42.1 (K), D49.1 (K), D56.1 (K), D63.1 (K), D70.1 (K), D77.1 (K), U1.11 (P1.04-LF)
V_BAT: J_BAT1.1, SW1.1 (A)

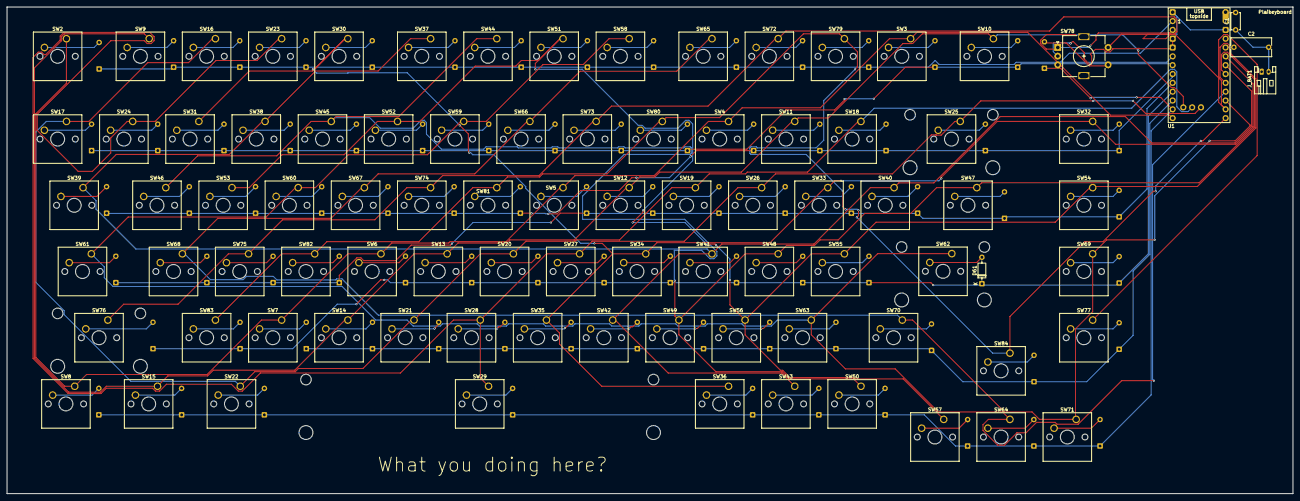
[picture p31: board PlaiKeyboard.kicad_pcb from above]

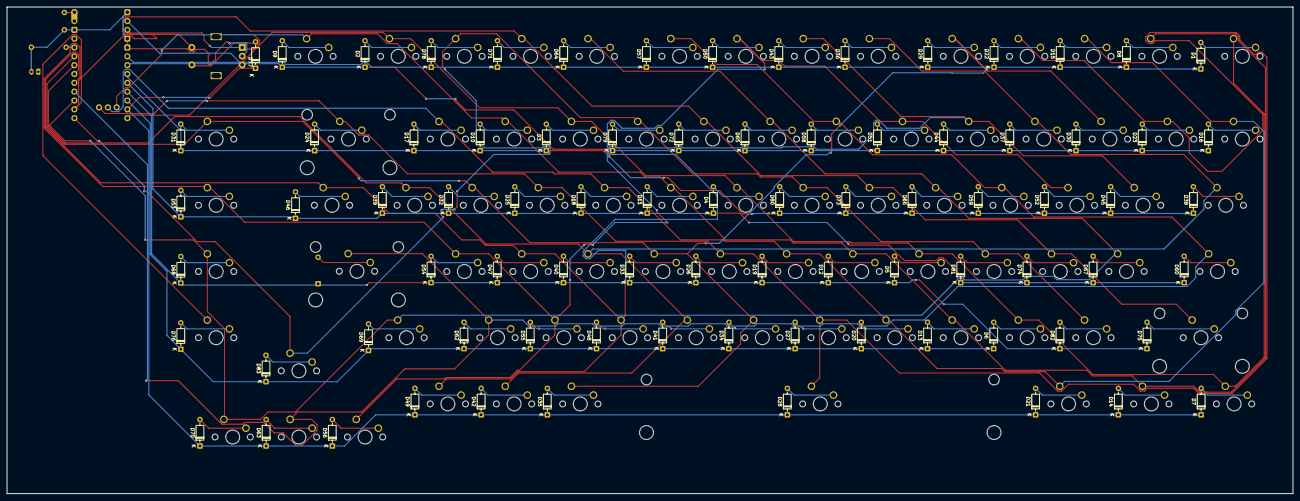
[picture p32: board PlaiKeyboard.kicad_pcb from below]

Board: 2 copper layers, 370.0 x 140.0 mm, 170 parts (82 on the bottom side), 107 nets.

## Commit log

2026-08-05 Add journal entry: Worked on keyboard schematic and layout
2026-08-05 Add journal entry: Ideas & Schematic
2026-08-07 Add journal entry: Added Rotary Encoder
2026-08-08 New Stuff
    [Keyboard.kicad_sch, PlaiKeyboard.kicad_pcb, PlaiKeyboard.kicad_sch]
2026-08-08 Add journal entry: Finished PCB
2026-08-08 Finished PCB!
    [2U Stabilizer.step, 6.25U Stabilizer.step, Cherry MX.IGS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]
2026-08-09 Second Try of keyboard
    [PlaiKeyboard.kicad_pcb, PlaiKeyboard.kicad_sch]
2026-08-09 Add journal entry: Redid PCB
2026-08-09 Redid the whole entire pcb and added new journal entries fixed some things and expanded the layout to a 75 percent layout exploded version
    [2U Stabilizer.step, 6.25U Stabilizer.step, Cherry MX.IGS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]
2026-08-09 git ignore
    [Cherry MX.STEP]
2026-08-12 ACTUALLY FINISHED WITH THE PCB
    [2U Stabilizer.step, 6.25U Stabilizer.step, Cherry MX.STEP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]
2026-08-27 Changed something
    [1.25u keycap.step, 1.5u keycap.step, 1.75u keycap.step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]
2026-08-29 Added the files for pcb prod and case prod
    [Bottom_Case.stl, PlaiKeyboard.kicad_pcb, Plate.stl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]
2026-08-29 New Changes
    [PlaiKeyboard.kicad_pcb, PlaiKeyboard.kicad_sch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]
